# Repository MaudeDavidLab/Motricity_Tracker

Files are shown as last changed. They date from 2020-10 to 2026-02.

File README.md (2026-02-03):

# UPDATE
Our institutional affiliations have changed. Please email gdeitzler@gmail.com or nbira13@gmail.com with questions regarding the manuscript.

# Motricity_Tracker
Source code and analysis pipeline for the low-cost voluntary running activity tracking system.

1. Arduino source code

2. Analysis pipeline in R

# Mousewheel Tracker Code Installation

### This README file functions to detail the process of installation of the Mousetracker Code on an Arduino Uno.

##### Author: Nicholas Bira, updated October 26th, 2020.

1) Have a current installation of the Arduino IDE [LINK](https://www.arduino.cc/en/main/software).
2) Download the relevant script, specifically EnableInterrupt_Mousewheels.ino, from the MaudeDavidLab GitHub repository.
3) Install the [EnableInterrupt](https://github.com/GreyGnome/EnableInterrupt) Library, required to enable the interrupt function on all pins of an Arduino or other microcontrollers.
4) Connect the relevant Arduino or microcontroller and upload the program, following standard procedure as documented on either the Arduino website or in the documentation of whichever microcontroller is being used.

# Conversion and Processing Pipeline

## This details the process of converting and processing raw data off the tracker into a usable format.

#### Author: Grace Deitzler, updated October 6th, 2021.

1) Have a current installation of R or RStudio (https://rstudio.com/products/rstudio/)
2) Download the conversion script Conversion_And_Processing.Rmd: https://github.com/MaudeDavidLab/Motricity_Tracker/blob/master/Conversion_and_Processing.Rmd.
3) If needed, install the relevant packages included in the script (ggplot2 and reshape2.)
4) Load the table into the read.table() command in the R Markdown script (line 25). You may load in a raw .txt file directly from the Arduino, or you may choose to open that file in Notebook or another text editing app first, and then save it as a .csv file. The script will take both.
4) Follow the rest of the instructions in the R Markdown file to convert your data. We have converted the numbers into miles for distance here, but you may choose to convert this into kilometers instead.

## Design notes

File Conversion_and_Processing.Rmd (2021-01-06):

---
title: "Conversion_and_Processing_MotricityScript"
author: "Grace E Deitzler"
date: "8/11/2020"
output: html_document
---

```{r setup, include=FALSE}
knitr::opts_chunk$set(echo = TRUE)
library(ggplot2)
library(reshape2)
```
# Conversion and Processing Tracker Data
## Introduction

This R script is used to convert and process the raw files that come off of the voluntary running tracker, and also provides a how-to guide on graphing the data. Once the tracker is done collecting data, the open terminal window can be closed and will be saved as a .txt file. This .txt file can be converted into a .csv and processed using the code below. Once it is processed it can be plotted and manipulated however is fitting for your interests. Here we show code for making a basic distance over time plot. Though we do not include it here, the file could also be manipulated to show speed or instantaneous velocity.

## Converting .txt file from Arduino

This first script will convert the raw .txt file that comes off the arduino into a usable .csv for further analysis. In some cases you may have to manually delete the first few extraneous rows of the .txt file that do not contain data. This can be done by opening the file in Notepad and then resaving it, or if you are working in RStudio, you can just open the file and delete the irrelevant rows. There may also be a row at the bottom that needs to be deleted as well. It is always best to manually check.

Due to the constraints of the Arduino, counts start at 0 and restart at 0 when 65535 is hit, so a continuous column of increasing numbers is not possible. This for loop goes through each column for each sensor, converting the raw arduino output to continously go up, as opposed to going back to 0 after it rolls over 65535. The output array, Data2, is then used for further processing and analysis.

```{r conversion}
tab = read.table("Validation_SeparateCages.csv", sep = ",") #fill in your file name here
Data2 = tab
for (j in 1:6){
  count = 0
  for (i in 1:(dim(tab)[1]-1)){
    Data2[i,j] = tab[i,j] +65535*count
    if (tab[i+1,j] < tab[i,j])
    {count <-count +1}
  }
  cat(j, " ")
}

diam_wheel = 4.5 # inches, estimated, need to have error included; change for your specific wheel
circum = diam_wheel*pi
circum_miles = circum*(1.57828e-5) #Circumference of the wheel in miles

# This converts Data2 from number wheel rotations to distance traveled in miles
Data2 = Data2*circum_miles

# This exports the final processed Data2 to a csv for further work.
write.csv(Data2, "Validation_SeparateCages.csv")
#This cage was run for 3 consecutive nights - aug 2 through the morning of aug 5

```

## Adding column names. time column, and trimming

In this step you can add column names (cage numbers, etc), and trim unused columns (if you did not use all 6 sensors.) The first column can also be trimmed as it just contains the row number. There is also a step to add in a column for Time. Since the sensor takes a measurement every 2 seconds and we run it overnight, we have converted here to hours.  

Optional: If you have multiple files that you want to combine into one dataframe, you may have to trim them all to be the same number of rows. 

All cages separate
```{r process}
#Read, rename, trim
df_separate<- read.csv("Validation_SeparateCages.csv", header=TRUE, sep=",")
df_separate <- df_separate[-c(1, 5:6)] #removes columns from sensors that were not used
colnames(df_separate) <-  c("Cage_1", "Cage_2", "Cage_3", "Cage_4")

#Add time
df_separate$Time <- (1:dim(df_separate)[1])/1800 #dividing makes it hours

#Trim to same length

#Save the new file
write.csv(df_separate, "Validation_Separate_Processed.csv")
```

## Plotting the distance over time

This is a simple plot to observe the total distance traveled over time as recorded by the sensor. This uses the ggplot2 package.

With all the mice together, the tracker was run from 8 PM Sunday evening to around 6 PM Tuesday evening.
```{r plotting,echo=FALSE}

#only sample once per hour
df_together1 <- df_together[seq(1, nrow(df_together), 1800),]
dim(df_together1)

df_tog_plot <- ggplot(df_together1, aes(Time, Single_Cage_Four_Mice)) + geom_line() +
  ggtitle("Single Cage, Four Mice") +
  xlab("Time (hours)") +
  ylab("Distance traveled (miles)")

df_tog_plot
  
```

The code presented here is merely a start. Other metrics can be assessed, such as velocity or speed, by manipulating the dataframe and using the appropriate plotting syntax.

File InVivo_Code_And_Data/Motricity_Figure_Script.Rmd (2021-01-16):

---
---
title: "Motricity_Figure_Script"
author: "Grace E Deitzler"
date: "12/10/2020"
output: html_document
---

```{r setup, include=FALSE}
library(ggplot2)
library(patchwork)
library(ggpubr)
library(ggsci)
library(reshape2)
library(hrbrthemes)
library(dplyr)
```

## Validation Experiment: in vivo

Read in the files, check, and relabel if needed

These files were already processed using the Conversion_and_Processing.Rmd script, which converted the raw .txt file from the Arduino into the .csv, added in a column for time, and converted the rotations to distance.

```{r read}
single <- read.csv("Validation_OneCage_Processed.csv") #all four mice in one cage

together <- read.csv("Validation_Separate_Processed.csv") #four mice, four cages

#check them

head(single)
head(together)

#there is a column called X that has the row number in it, don't know if we need that right now
```

We ran this tracker over two nights and two days, so we want to only sample every 5 minutes to make the graph more readable.

```{r}
#removing extra hours that I left the tracker on

single_five <-  single[seq(1, nrow(single), 100),]

#removing extra hours that I left the tracker on
together_mod <- together[-c(91265:122435),]
together_five <- together_mod[seq(1, nrow(together_mod), 100),]

write.csv(single_five, file = "single_cage.csv")
write.csv(together_five, file = "four_cages.csv")
```

## Plots

We want to compare the distances run in each validation experiment. The columns contatining the number of rotations has already been converted to miles, so we don't have to do this here.

```{r plots, echo=FALSE}

onecage <- ggplot(data = single_five, aes(x = Time, y = Single_Cage_Four_Mice)) +
         geom_line(color = "#3D5A80", size = 2, alpha = 0.9) +
  scale_x_continuous(breaks = c(0,6,12,18,24,30,36,42,48),
                     labels=c("12 PM", "6 PM", "12 AM", "6 AM", "12 PM", "6 PM", "12 AM", "6 AM", "12 PM")) +
         ggtitle("All mice in a single cage") +
         xlab("Time (hours)") +
        ylab("Distance (mi)") +
  theme_ipsum(axis_title_just = "c")

#ggsave("onecage.tiff", dpi = 300, plot = onecage)

onecage
ggsave("fig3b.png", plot = onecage, width = 7, height = 4, dpi = 300, units = "in", device="png")
```

```{r}

#We need to melt the four cages

melt_together_five <- melt(together_five, id.vars = "Time", measure.vars = c("Cage_1", "Cage_2", "Cage_3", "Cage_4"))

head(melt_together_five)
colnames(melt_together_five) <- c("Time", "Cage", "Distance")

fourcage <- ggplot(data = melt_together_five, aes(x = Time, y = Distance, color = Cage)) +
         geom_line(size = 2, alpha = 0.9) +
   scale_x_continuous(breaks = c(0,6,12,18,24,30,36,42,48),
                     labels=c("12 PM", "6 PM", "12 AM", "6 AM", "12 PM", "6 PM", "12 AM", "6 AM", "12 PM")) +
  scale_color_motricity(palette = "four") +
         ggtitle("Four mice in separate cages") +
  ylim(0,10)+
         xlab("Time (hours)") +
        ylab("Distance (mi)") +
  theme_ipsum(axis_title_just = "c")

#ggsave("fourcage.tiff", dpi = 300, plot = fourcage)

fourcage
ggsave("fig3a.png", plot = fourcage, width = 7, height = 4, dpi = 300, units = "in", device="png")
```

```{r}
fig3 <- onecage + fourcage
fig3 <- fig3 + plot_annotation(tag_levels = 'A')

fig3

ggsave("fig3.eps", plot = fig3, device = "eps", width = 5, height = 4, units = "in")

```

## Caloric Restriction 

We have four cohorts, each which were tracked at baseline and at 4 days of 80% caloric restriction. We want to plot a bar chart to compare the total distance ran by baseline and by starved.

Here we are taking the data from Baseline on June 18, and the subsequent data from the days following the starvation period on June 22. 

First, process the csv files, label and combine where needed.

```{r baseline}
df_baseline <- read.csv("df_baseline.csv")

df_baseline$Condition <- "Baseline"

```

Now the restriction
```{r restriction}
df_restriction <- read.csv("df_restriction.csv")

df_restriction$Condition <- "Caloric restriction"

```

Now that we have two data frames, one for baseline and one for starved, we can melt them down into the proper format for doing a line plot.

```{r}
melt_baseline <- melt(df_baseline, id.vars = "Time", measure.vars = c("Cage 1", "Cage 2", "Cage 3", "Cage 4", "Cage 5", "Cage 6", "Cage 7", "Cage 8"))

melt_restriction <- melt(df_restriction, id.vars = "Time", measure.vars = c("Cage 1", "Cage 2", "Cage 3", "Cage 4", "Cage 5", "Cage 6", "Cage 7", "Cage 8"))

colnames(melt_baseline) <- c("Time", "Cage", "Distance")
melt_baseline$Condition <-  "Baseline"

colnames(melt_restriction) <- c("Time", "Cage", "Distance")
melt_restriction$Condition <- "Caloric restriction"
```

We can now make a plot of each of these. 

```{r}
baseline <- ggplot(data = melt_baseline, aes(x = Time, y = Distance, color = Cage)) +
         geom_line(size = 1.5) +
  scale_color_motricity(palette = "main") +
         ggtitle("Baseline: before caloric restriction") +
  ylim(0,10)+
  xlim(0,10)+
         xlab("Time (hours)") +
        ylab("Distance (mi)") +
  theme_ipsum(axis_title_just = "c") +
  theme(legend.position = "none")
baseline

```

```{r}
restriction <- ggplot(data = melt_restriction, aes(x = Time, y = Distance, color = Cage)) +
         geom_line(size = 1.5) +
  scale_color_motricity(palette = "main") +
         ggtitle("After caloric restriction") +
  ylim(0,10)+
  xlim(0,10)+
         xlab("Time (hours)") +
        ylab("Distance (mi)") +
  theme_ipsum(axis_title_just = "c") +
  theme(legend.title = element_blank())
restriction
```
Now I want to do the barplot, but first we have to get the data into the right format. We'll need to group them by condition - baseline and restriction - and "cage" should be it's own column. I think we can do this if we add in a category column to each of the melted dfs and then combine them.

```{r}

#Dataframe with both of them, we will call it 'compare.br' with the br referring to 'baseline' and 'restriction'
compare.br <- rbind(melt_baseline, melt_restriction)

```

Attempting a different kind of plot here. Need to rearrange the dataframe first, to extract just the final distance.

```{r}

cut_baseline <- df_baseline[rownames(df_baseline) == 20334, , drop = FALSE]
cut_restriction <- df_restriction[rownames(df_restriction) == 20334, , drop = FALSE]

compare.df <- rbind(cut_baseline, cut_restriction)

melt_compare <- melt(compare.df, id.vars = "Condition", measure.vars = c("Cage 1", "Cage 2", "Cage 3", "Cage 4", "Cage 5", "Cage 6", "Cage 7", "Cage 8"))

colnames(melt_compare) <- c("Condition", "Cage", "Distance")

```

Excellent, I think this worked?

Now I want to make a scatter plot with connected dots to show the paired data

```{r}
#trying the ggpaired function

#ggpaired(compare.df, cond1 = "Baseline", cond2 = "Caloric restriction", fill = "Condition") 

#now trying something else

compare.points <- ggplot(data = melt_compare_minus, aes(x = Condition, y = Distance)) +
   geom_line(aes(group = Cage)) +
  geom_point(size = 4, aes(color = Cage)) +
  scale_color_motricity() +
  ylab("Total distance (mi)") +
  ggtitle("Total distance before and after caloric restriction") + 
  theme_ipsum(axis_title_just = "c")

compare.points
```

Put it all together using Patchwork

```{r}
fig4 <- (baseline | restriction) /
  compare.points

fig4 <- fig4 + plot_annotation(tag_levels = 'A')
fig4

ggsave("fig4.eps", fig4, device = "eps", width = 11, height = 8.5)
```

Save all the things
```{r}
ggsave("fig3A_edit.png", dpi = 300, plot = onecage)
ggsave("fig3B_edit.png", dpi = 300, plot = fourcage)
ggsave("fig4A_edit.png", dpi = 300, plot = baseline)
ggsave("fig4B_edit.png", dpi = 300, plot = restriction)
ggsave("fig4C_edit.png", dpi = 300, plot = compare.points)
```

# Statistical analysis

```{r}

before <- subset(melt_compare,  Condition == "Baseline", Distance,
                 drop = TRUE)
# subset weight data after treatment
after <- subset(melt_compare,  Condition == "Caloric restriction", Distance,
                 drop = TRUE)
res_compare <- wilcox.test(before, after, paired = TRUE)
res_compare
```

Cage 5 had a mechanical failure on the second night - remove from the data

```{r}
melt_compare_minus <- melt_compare[-c(9:10), ]

ggboxplot(melt_compare_minus, x = "Condition", y = "Distance", 
          color = "Condition", palette = c("#00AFBB", "#E7B800"),
          order = c("Baseline", "Caloric restriction"),
          ylab = "Distance", xlab = "Groups")

```

stats without cage 5:

```{r}
before2 <- subset(melt_compare_minus,  Condition == "Baseline", Distance,
                 drop = TRUE)
# subset weight data after treatment
after2 <- subset(melt_compare_minus,  Condition == "Caloric restriction", Distance,
                 drop = TRUE)
res_compare_minus <- wilcox.test(before, after, paired = TRUE)
res_compare_minus
```

Permutation: switch all the labels before and after randomly - look at the mean of the diff vector after that
```{r}
mean(diff_no5)

saveRDS(melt_compare_minus, file = "melt_compare_minus.rds")
sample(melt_compare_minus$Condition) #shuffle labels
perm <- c()

for (i in 1:1000){
cat(i," ")
df1 <- melt_compare_minus
df1$Condition <- sample(df1$Condition)

tmp <- mean(df1$Distance[df1$Condition == "Caloric restriction"]-df1$Distance[df1$Condition == "Baseline"])

perm <- c(perm,tmp)
}

perm
```

Density plot
```{r}
plot(density(perm)); abline(v = 2.215)
```

Now we will try to calculate the area under the curve beyond the abline.
```{r}
d_fun <- ecdf(perm) #create the empirical cumulative distribution from sample data

x0 <- 2.215 #assume a value for the vertical line (which is the mean of our real data)

d_fun(x0) #area under curve less than or equal to x0

1-d_fun(x0)
```

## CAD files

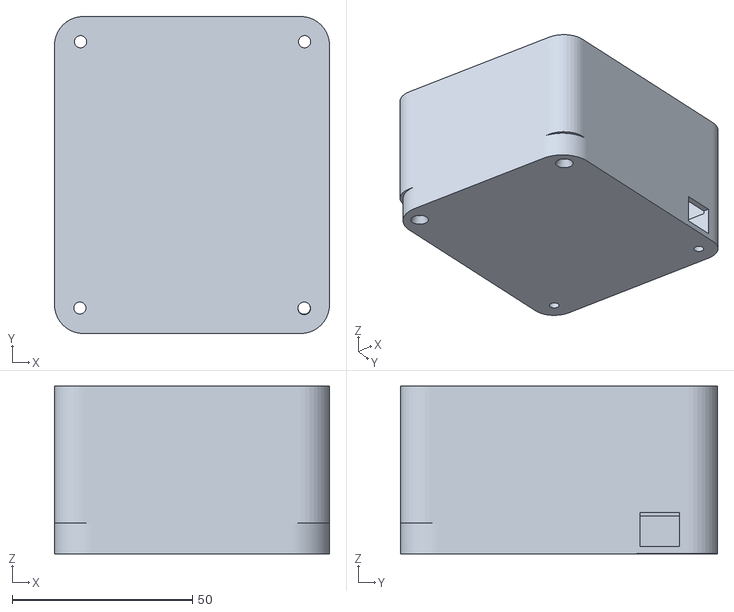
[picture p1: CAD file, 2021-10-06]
Arduino_Tracker_Box.STL
76.3 x 87.9 x 46.5

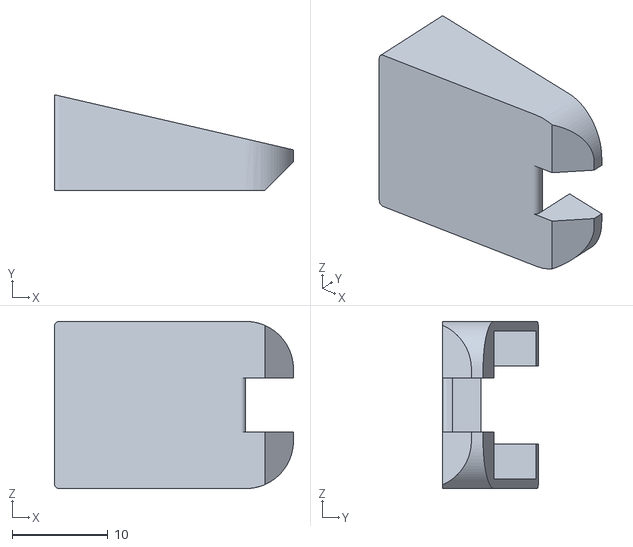
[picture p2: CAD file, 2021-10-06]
Sensor_Cover.STL
25.0 x 10.0 x 17.5

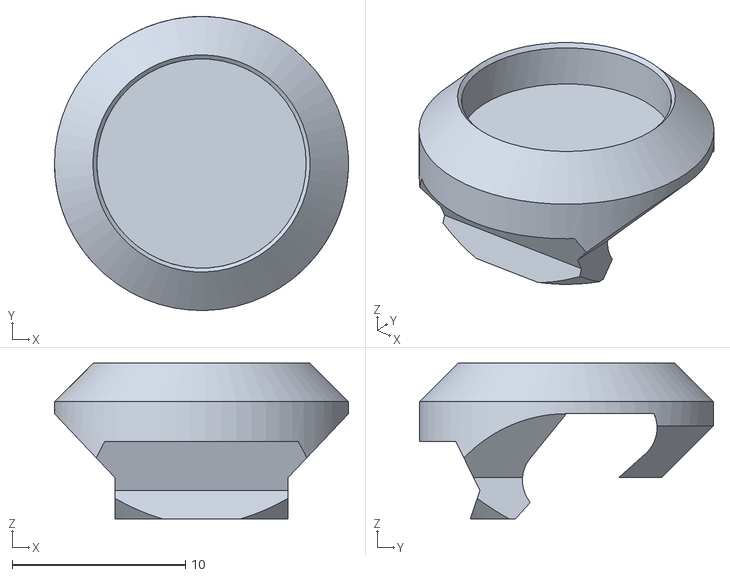
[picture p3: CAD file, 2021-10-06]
MagnetHolderV3.STL
17.0 x 17.0 x 9.00

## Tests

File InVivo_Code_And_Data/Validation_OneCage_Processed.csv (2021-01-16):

 | Single_Cage_Four_Mice | Time
1 | 0 | 0.000555555555555556
2 | 0 | 0.00111111111111111
3 | 0 | 0.00166666666666667
4 | 0 | 0.00222222222222222
5 | 0.000446248156797693 | 0.00277777777777778
6 | 0.000892496313595386 | 0.00333333333333333
7 | 0.00111562039199423 | 0.00388888888888889
8 | 0.00111562039199423 | 0.00444444444444444
9 | 0.00111562039199423 | 0.005
10 | 0.00111562039199423 | 0.00555555555555556
11 | 0.00133874447039308 | 0.00611111111111111
12 | 0.00133874447039308 | 0.00666666666666667
13 | 0.00178499262719077 | 0.00722222222222222
14 | 0.00178499262719077 | 0.00777777777777778
15 | 0.00178499262719077 | 0.00833333333333333
16 | 0.00178499262719077 | 0.00888888888888889
17 | 0.00200811670558962 | 0.00944444444444444
18 | 0.00223124078398846 | 0.01
19 | 0.00223124078398846 | 0.0105555555555556
20 | 0.00245436486238731 | 0.0111111111111111
21 | 0.00245436486238731 | 0.0116666666666667
22 | 0.00267748894078616 | 0.0122222222222222
23 | 0.00267748894078616 | 0.0127777777777778
24 | 0.002900613019185 | 0.0133333333333333
25 | 0.0033468611759827 | 0.0138888888888889
26 | 0.0033468611759827 | 0.0144444444444444
27 | 0.0033468611759827 | 0.015
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

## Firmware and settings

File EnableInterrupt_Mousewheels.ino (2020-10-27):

// This code was written by Nicholas Bira, August 24, 2020. It builds on example sketches from the EnableInterrupt library.
// This code allows for six constantly updating sensors, tracking rotations of six wheels. This is easily scalable. 
// More elegant methods are possible; refer to https://github.com/GreyGnome/EnableInterrupt/wiki/Usage#Summary
// Library downloaded from: https://bintray.com/greygnome/generic/EnableInterrupt/view#files

#include <EnableInterrupt.h>

volatile uint16_t interruptCount1=0;
volatile uint16_t interruptCount2=0;
volatile uint16_t interruptCount3=0;
volatile uint16_t interruptCount4=0; 
volatile uint16_t interruptCount5=0; 
volatile uint16_t interruptCount6=0; 

// For all variables, the count will go back to 0 after hitting 65535. Account for this in post-processing.

void interruptFunction1() {
  interruptCount1++;
}

void interruptFunction2() {
  interruptCount2++;
}

void interruptFunction3() {
  interruptCount3++;
}

void interruptFunction4() {
  interruptCount4++;
}

void interruptFunction5() {
  interruptCount5++;
}

void interruptFunction6() {
  interruptCount6++;
}

void setup() {
  Serial.begin(115200);

  pinMode(4, INPUT_PULLUP);  // See http://arduino.cc/en/Tutorial/DigitalPins
  pinMode(5, INPUT_PULLUP); 
  pinMode(6, INPUT_PULLUP); 
  pinMode(8, INPUT_PULLUP); 
  pinMode(9, INPUT_PULLUP); 
  pinMode(10, INPUT_PULLUP); 

  enableInterrupt(4, interruptFunction1, RISING);
  enableInterrupt(5, interruptFunction2, RISING);
  enableInterrupt(6, interruptFunction3, RISING);
  enableInterrupt(8, interruptFunction4, RISING);
  enableInterrupt(9, interruptFunction5, RISING);
  enableInterrupt(10, interruptFunction6, RISING);
}

// The loop prints the number of rotations for each sensor every 2 seconds. The value is updated by the interrupt routine.
void loop() {
  Serial.print(interruptCount1);
  Serial.print(", ");
  Serial.print(interruptCount2);
  Serial.print(", ");
  Serial.print(interruptCount3);
  Serial.print(", ");
  Serial.print(interruptCount4);
  Serial.print(", ");
  Serial.print(interruptCount5);
  Serial.print(", ");
  Serial.println(interruptCount6);
  delay(2000);
}

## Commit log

2021-01-16 Add files via upload
    data, code for robotic validation
    [Motor_Verification_Data_Distance.csv, Motor_Verification_Data_Velocity.csv]
2021-01-16 in vivo validation CORRECT
    [Validation_OneCage_Processed.csv, df_baseline.csv, df_restriction.csv]
2021-10-06 .STL files
    .STL files for 3D printing tracker system components
    [Arduino_Tracker_Box.STL, MagnetHolderV3.STL, Sensor_Cover.STL]
